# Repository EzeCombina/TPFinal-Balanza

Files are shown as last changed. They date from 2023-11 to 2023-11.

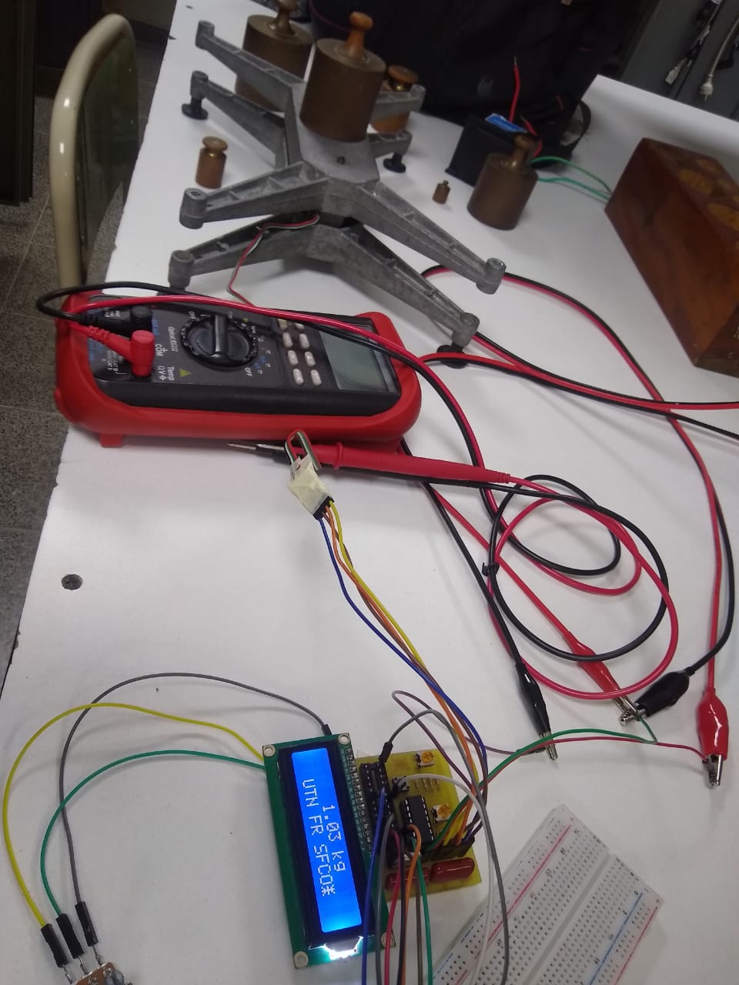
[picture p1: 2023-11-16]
Imágenes y Videos/1kg.jpeg

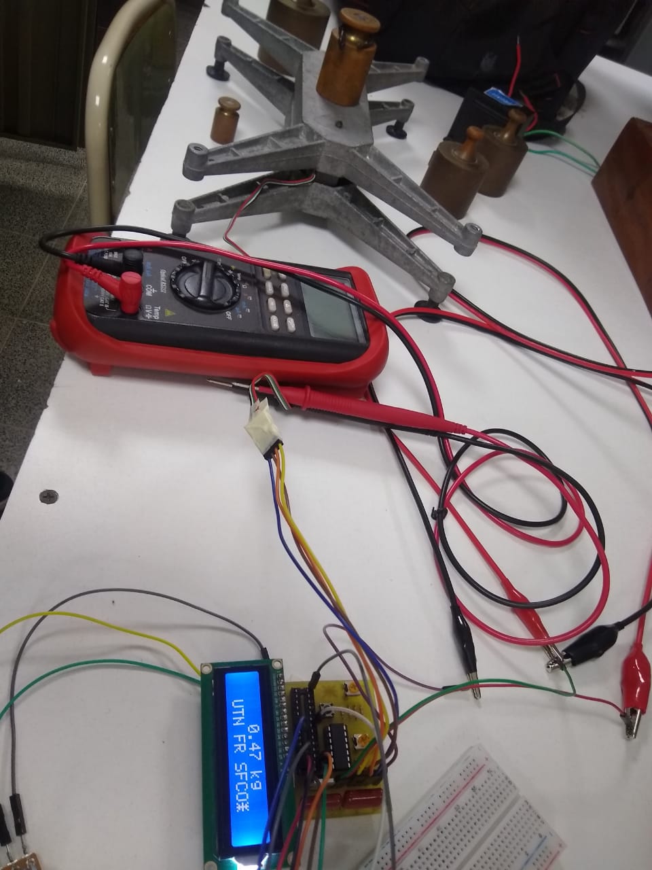
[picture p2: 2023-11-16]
Imágenes y Videos/500g.jpeg

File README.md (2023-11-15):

# Balanza 0-30 Kg
## Trabajo práctico final de Electrónica Aplicada II y Teoría de Circuitos II. UTN FR San Francisco
En este repositorio se encuentran subidos todos los archivos relacionados al trabajo práctico de amplificadores operacionales de Electrónica Aplicada II y filtros digitales de Teoría de Circuitos II. Contiene archivos de programación del microcontrolador ATMega328p, archivos de la placa realizada en KiKad, la simulación en Multisim del amplificador de instrumentación y el programa de cálculo del filtro en Octave.
## Autores
- Combina Ezequiel
* Giorgis Guillermo

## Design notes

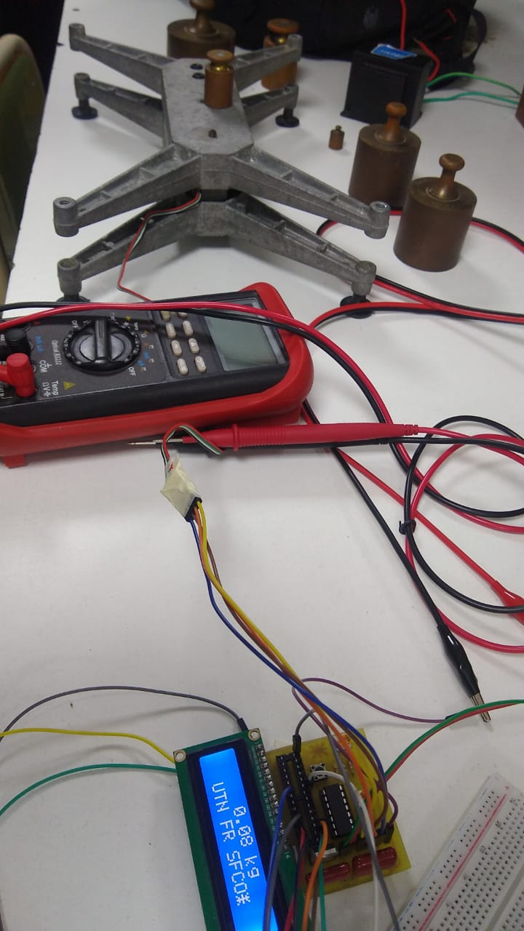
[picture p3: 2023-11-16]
Imágenes y Videos/100g.jpeg

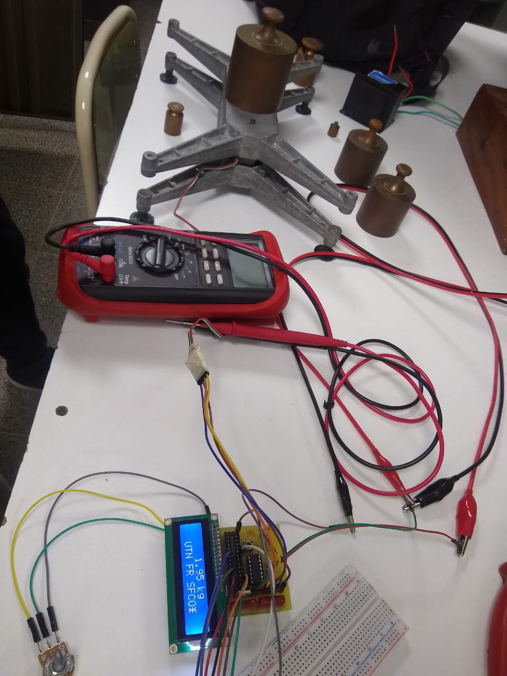
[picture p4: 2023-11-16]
Imágenes y Videos/2kg.jpeg

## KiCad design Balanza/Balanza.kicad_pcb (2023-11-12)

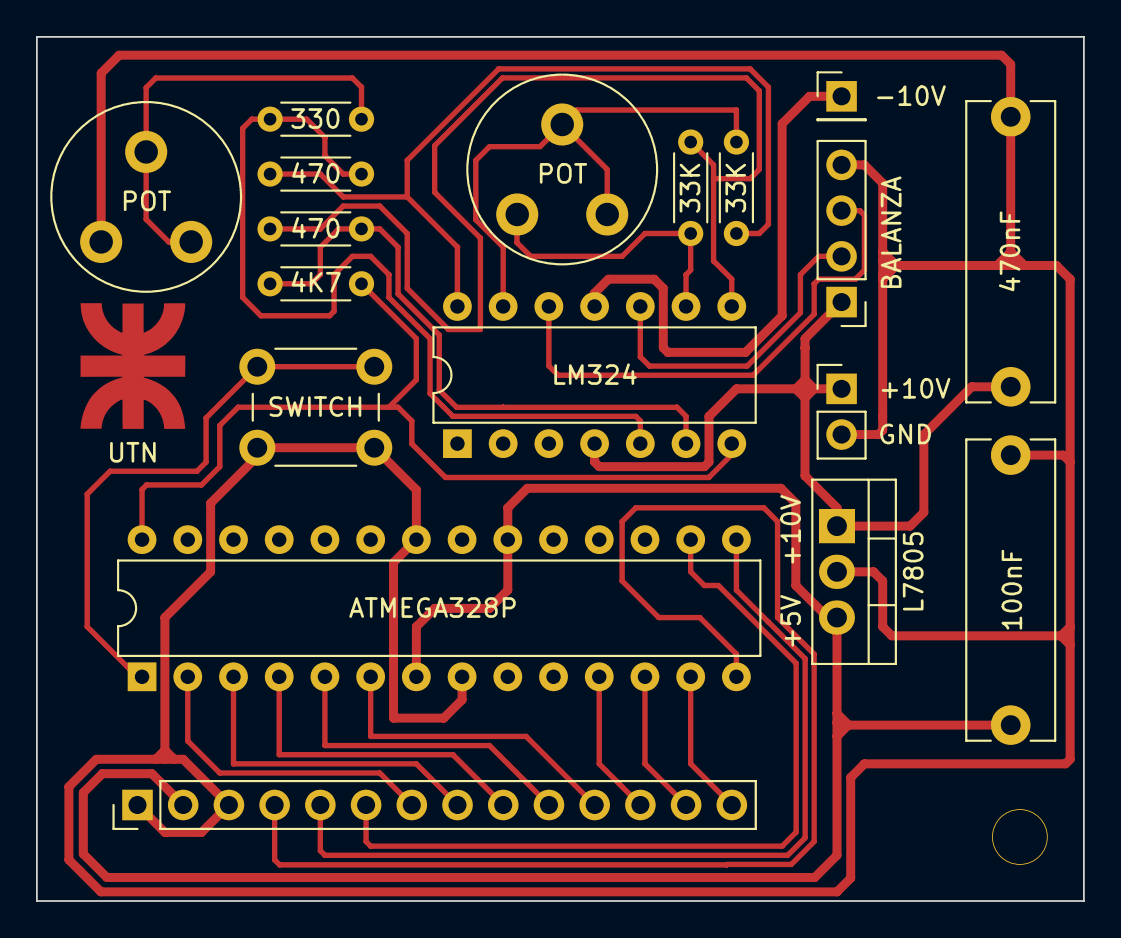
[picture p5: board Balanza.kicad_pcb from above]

Board: 2 copper layers, 58.2 x 48.0 mm, 18 parts (0 on the bottom side), 26 nets.

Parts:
4K7, 330: 4K7; R_Axial_DIN0204_L3.6mm_D1.6mm_P5.08mm_Horizontal
33K, 33K#2: 33K; R_Axial_DIN0204_L3.6mm_D1.6mm_P5.08mm_Horizontal
100nF: 100nF; C_Rect_L16.5mm_W4.7mm_P15.00mm_MKT
470, 470#2: 470; R_Axial_DIN0204_L3.6mm_D1.6mm_P5.08mm_Horizontal
470nF: 470nF; C_Rect_L16.5mm_W4.7mm_P15.00mm_MKT
+10V: Conn_01x02_Male; PinHeader_1x02_P2.54mm_Vertical
-10V: Conn_01x01_Male; PinHeader_1x01_P2.54mm_Vertical
ATMEGA328P: ATmega328P-P; DIP-28_W7.62mm
BALANZA: Conn_01x04_Male; PinHeader_1x04_P2.54mm_Vertical
J1: Conn_01x14_Male; PinHeader_1x14_P2.54mm_Vertical
L7805: L7805; TO-220-3_Vertical
LM324: LM324; DIP-14_W7.62mm
POT: R_Variable; Potentiometer_Piher_PT-10-V05_Vertical
POT#2: R_Variable; Potentiometer_Piher_PT-10-V05_Vertical
SWITCH: SW_Push_Dual_x2; SW_PUSH_6mm

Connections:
+5V: 100nF.1, ATMEGA328P.7 (VCC), ATMEGA328P.20 (AVCC), J1.2, L7805.3 (OUT)
+10V: 470nF.1, +10V.1, BALANZA.1, L7805.1 (IN), LM324.4 (V+)
/ADC: 4K7.1, ATMEGA328P.28 (PC5), LM324.7
/Data+: BALANZA.3, LM324.12 (+)
/Data-: BALANZA.2, LM324.10 (+)
/PB0 RS: ATMEGA328P.14 (PB0), J1.4
/PB1 RW: ATMEGA328P.15 (PB1), J1.5
/PB2 E: ATMEGA328P.16 (PB2), J1.6
/PD0: ATMEGA328P.2 (PD0), J1.7
/PD1: ATMEGA328P.3 (PD1), J1.8
/PD2: ATMEGA328P.4 (PD2), J1.9
/PD3: ATMEGA328P.5 (PD3), J1.10
/PD4: ATMEGA328P.6 (PD4), J1.11
/PD5: ATMEGA328P.11 (PD5), J1.12
/PD6: ATMEGA328P.12 (PD6), J1.13
/PD7: ATMEGA328P.13 (PD7), J1.14
/RESET: ATMEGA328P.1 (~RESET/PC6), SWITCH.1 (C)
/Vcc_-10V: -10V.1, LM324.11 (V-)
Earth: 100nF.2, 470nF.2, +10V.2, ATMEGA328P.8 (GND), ATMEGA328P.22 (GND), BALANZA.4, J1.1, J1.3, L7805.2 (GND), POT.3, SWITCH.2 (D)
unnamed: 33K.1, LM324.9 (-), POT#2.3
unnamed: 33K.2, 470.2, LM324.8
unnamed: 33K#2.1, 470#2.2, LM324.14
unnamed: 4K7.2, 470.1, LM324.6 (-)
unnamed: 330.2, 470#2.1, LM324.5 (+)
unnamed: 330.1, POT.1, POT.2
unnamed: 33K#2.2, LM324.13 (-), POT#2.1, POT#2.2

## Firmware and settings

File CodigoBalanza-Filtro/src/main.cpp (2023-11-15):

#include <Arduino.h>
#include <LiquidCrystal.h>

#define TiempoMuestreoMS 9.09

const char pinRs = 8;         // PB0
const char pinRw = 9;         // PB1
const char pinE = 10;         // PB2
const char pinD4 = 4;         // PD4
const char pinD5 = 5;         // PD5
const char pinD6 = 6;         // PD6
const char pinD7 = 7;         // PD7
const char pinADC = A5;       // PC5

// Logo UTN

byte UTN[8] {

  B10101,
  B01110,
  B00100,
  B11111,
  B00100,
  B01110,
  B10101,
  B00000
  
};

//

//const float CoefEntrada[5] = {0.2194, 0.8778, 1.3167, 0.8778, 0.2194};
//const float CoefSalida[5] = {1, -1.1989, -0.9437, -0.3194, -0.049};

const float CoefEntrada[5] = {0.1237, 0.4949, 0.7423, 0.4949, 0.1237};
const float CoefSalida[5] = {1, -0.3566, -0.5262, -0.07653, -0.02015};

float ArrayEntrada[5] = {0, 0, 0, 0, 0};
float ArraySalida[5] = {0, 0, 0, 0, 0}; 

float Peso = 0.0;
float valorAntiguo = 0.0;

LiquidCrystal lcd(pinRs, pinRw, pinE, pinD4, pinD5, pinD6, pinD7);

unsigned long TiempoMedido = 0;

void calculopeso(float valorADC){

  //if((valorADC < valorAntiguo + 0.5) && (valorADC > valorAntiguo - 0.5))
  //{
  //  valorADC = valorAntiguo;
  //}

  // --- Cálculos para evitar errores en la medición --- Habria que realizar una función de linealización //

  valorADC = valorADC - 9.5;

  if(valorADC <= 0.1){

    Peso = 0.0;

  }else if(valorADC < 30)
  {
    
    Peso = (valorADC + 2) * 30 / 1023;
  
  }else if(valorADC > 100)
  {
    
    Peso = (valorADC + 10) * 30 / 1023;
    
  }else{Peso = (valorADC + 5) * 30 / 1023;}

  //valorAntiguo = valorADC;

  /*
  valorADC = valorADC - 11;
  if(valorADC <= 0.1){

    Peso = 0.0;

  }else{Peso = (valorADC + 5) * 30 / 1024;}
  */

  //float Peso = (valorADC + 1) * 30 / 1024;

  // --- Evitar que parpadee --- //

  if((Peso < valorAntiguo + 0.025) && (Peso > valorAntiguo - 0.025)) 
  {
    Peso = valorAntiguo;
  }

  lcd.setCursor(0,0);
  lcd.print("     ");
  lcd.print(Peso, 2);
  lcd.print(" kg    ");

  valorAntiguo = Peso;

}

void datosEntrada(){
  TiempoMedido = millis();
  ArrayEntrada[0] = float(analogRead(pinADC));
}

void filtro(){
  float sumatoria = CoefEntrada[0]*ArrayEntrada[0];
  for(int i = 1; i < 5; i++){
    sumatoria += CoefEntrada[i] * ArrayEntrada[i] + CoefSalida[i] * ArraySalida[i];
  }
  ArraySalida[0] = sumatoria;
}

void corrimientoArray(){
  for(int i = 4; i > 0; i--){
    ArraySalida[i] = ArraySalida[i-1];
    ArrayEntrada[i] = ArrayEntrada[i-1];
  }
}

void pines(){
  pinMode(pinADC, INPUT);
  pinMode(pinRs, OUTPUT);
  pinMode(pinRw, OUTPUT);
  pinMode(pinE, OUTPUT);
  pinMode(pinD4, OUTPUT);
  pinMode(pinD5, OUTPUT);
  pinMode(pinD6, OUTPUT);
  pinMode(pinD7, OUTPUT);
}

void inicializacionLCD(){
  lcd.begin(16, 2);
  lcd.setCursor(0, 1);
  lcd.print("  UTN FR SFCO");
  lcd.write(byte(0));
}

void setup() {
  pines();
  lcd.createChar(0, UTN);
  //lcd.clear();
  inicializacionLCD();
  TiempoMedido = millis();
  Serial.begin(9600);
}

void loop() {
  if(millis() - TiempoMedido >= TiempoMuestreoMS){
    datosEntrada();
    filtro();
    Serial.println(ArraySalida[0]);
    calculopeso(ArraySalida[0]);
    corrimientoArray(); 
  }
}

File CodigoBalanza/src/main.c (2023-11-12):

#include <Arduino.h>
#include <avr/io.h>
#include <util/delay.h>
#include <stdio.h>
#include <stdlib.h>
#include <avr/interrupt.h>
#include <stdint.h>
#include "../lib/ftoa/ftoa.h"
#include "../lib/lcd/lcd.h"
// #include <Arduino.h>


/*
    PORTB -> Control
    PB2: E
    PB1: R/W -> 0: write
    PB0: RS
*/
/*
    PORTD -> D[7-0]
*/

const int pos_flechaAbajo = 1;
const int pos_flechaArriba = 2;
const int pos_logoUTN = 3;


void ADC_initialization(uint8_t pin)
{
    // voltage ref: AVCC
    // conversion left adjusted: 10 bits
    // ADMUX[3:0]: pin a5
    ADMUX = 0x45; // 0100_0101
    // ADCSRA[7]: enable adc
    // ADCSRA[3]: enable interrupts
    // ADCSRA[2:0]: prescaler (128)
    ADCSRA = 0x87; // 1000_0111
    DIDR0 |= 1 << pin;
}

/// @brief Compara la temp con la anterior y muestra una flecha indicando si sube o baja
int compare_result(int result, int old_weight)
{
    if (result == old_weight)
    {
        lcd_data(' ');
        return 0;
    }

    // muestra la flecha indicando si la temp subio o bajo
    if (result > old_weight)
    {
        lcd_data(pos_flechaArriba);
    }
    else
    {
        lcd_data(pos_flechaAbajo);
    }

    return 1;
}

void printUTN()
{
    // salta a 2da linea, pos 3
    // LCD_8bits_comando(0xC3);
    lcd_cmd(0xC3);

    lcd_print("UTN FR SFCO");
    lcd_data(pos_logoUTN);

    lcd_cmd(0b10001010);
    lcd_print("KG");
}

int main()
{    
    uint8_t lower_bits;
    uint8_t higher_bits;
    uint16_t adc_result;

    float weight;
    float old_weight = 0;
    float temp_weight = 0;

    int counter = 1;
    char temp_str[5];

    ADC_initialization(5);

    // LCD_8bits_on();
    lcd_init();

    // flecha 1
    char flechaAbajo[8] = {0x04, 0x04, 0x04, 0x04, 0x1F, 0x0E, 0x04, 0x00};
    char flechaArriba[8] = {0x04, 0x0E, 0x1F, 0x04, 0x04, 0x04, 0x04, 0x00};
    // logo utn
    char logoUTN[8] = {0x15, 0x0E, 0x04, 0x1F, 0x04, 0xE, 0x15, 0x00};

    // LCD_8bits_Crea_Caracter(pos_flechaAbajo, flechaAbajo);
    lcd_create_char(pos_flechaArriba, flechaArriba);
    lcd_create_char(pos_flechaAbajo, flechaAbajo);
    lcd_create_char(pos_logoUTN, logoUTN);

    printUTN();

    while (1)
    {
        // ADCSRA[6] = 1 -> inicia una conversion
        ADCSRA |= 1 << ADSC;
        // ADIF -> interr flag, alta cuando termina la conversion
        while ((ADCSRA & (1 << ADIF)) == 0)
            ;

        lower_bits = ADCL;
        higher_bits = ADCH;
        adc_result = (higher_bits << 8) | lower_bits;
        weight = (adc_result + 0.01) * 30 / 1024;
        temp_weight += weight;

        if (counter++ % 4 != 0)
            continue;

        // entra cada 4 lecturas, entonces toma el promedio
        weight = temp_weight / 4;


        // LCD_8bits_comando(0b10000011);
        lcd_cmd(0b10000011);

        if (compare_result(weight, old_weight))
        {
            old_weight = weight;
            // actualiza el peso
            ftoa(weight, temp_str);
            lcd_print(temp_str);
        }

        // vuelve al inicio
        lcd_cmd(0x02);

        // reseteo el contador y el sumador
        counter = 1;
        temp_weight = 0;
        _delay_ms(500);
    }
}
